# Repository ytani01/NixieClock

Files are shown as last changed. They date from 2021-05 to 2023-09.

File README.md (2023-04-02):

# NixiClock

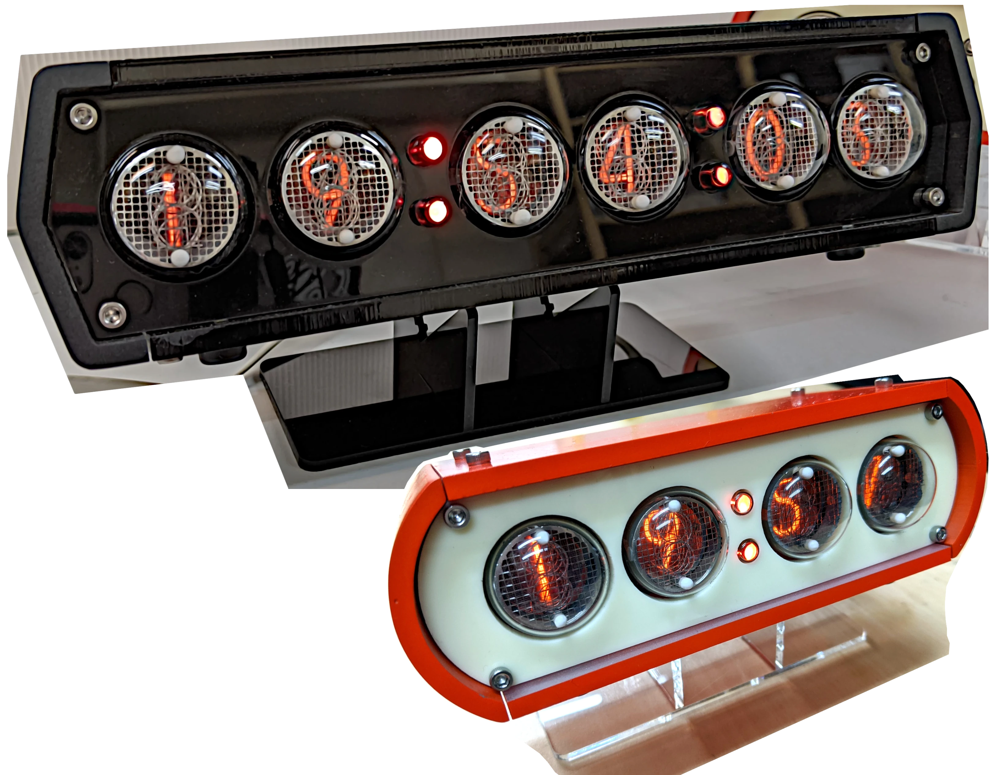
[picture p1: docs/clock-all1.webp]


現在入手困難な、本物のニキシー管を使った時計です。

レトロな外観ではありますが、
WiFi経由でインターネット上の時刻サーバーから、
正確な時刻を取得して、
常に正確な時刻を刻みます。

* WiFi経由で、自動的に時刻合わせ

  インターネット上の時刻サーバー(NTPサーバー)から
  正確な時刻を取得するので、時刻合わせが不要です。
  
  WiFi設定は、スマホで行います。

  (WiFi環境がない場合は、マニュアルで時刻設定することもできます。)

* 明るさの調節

  暗い部屋で眩しいときは、明るさを調整できます。

* 日付表示 可能

## 1. コロン表示の意味

* 【日付表示のとき点滅】WiFi接続 OK

  インターネット経由で、自動的に時刻合わせが行われています。
  
  [ボタン0] ダブルクリックで、``WiFi設定モード``にすることで、
  自動的な時刻合わせを停止することもできます
  (インターネット通信を停止します)。

* 【日付表示のとき点灯】WiFi接続 なし (WiFi設定モード)

  スマホを使って、本時計の WiFiを設定するか、
  マニュアル操作で時刻を設定してください。

  設定した時刻は、電源を切っても保存されます。

  WiFi設定ができているのに、電波の状態などで接続が切れた場合は、
  [ボタン0] ダブルクリックすると、時計が再起動し、WiFi接続を試みます。

## 2. 操作法

## 2.1. ボタン概要

時計表示のとき
```
   +---------- [ボタン0] 日付表示 | ダブルクリック:WiFi設定 | 長押し:手動時刻合わせ
   |  +------- [ボタン1] 日付表示
   |  |  +---- [ボタン2] 明るさ変更 | ダブルクリック:バクライトON/OFF(6桁モデル)
   |  |  |
 --v--v--v--
|  o  o  o  |
 -----------
```

手動で時刻を合わせるとき
```
   +---------- [ボタン0] 長押し: 時刻合わせキャンセル
   |  +------- [ボタン1] 年 -> 月 -> 日 -> 時 -> 分 -> [確定]
   |  |  +---- [ボタン2] カウントアップ
   |  |  |
 --v--v--v--
|  o  o  o  |
 -----------
```

## 2.2 日付表示 [ボタン1]

[ボタン1]を押すと、「年:月:日」を表示します。

数秒後に、時刻表示に戻ります。

## 2.3 明るさ変更 [ボタン2]

明るさを変更(サイクリック)

### 2.4 時刻合わせ (WiFi環境がある場合)

WiFi経由でインターネットに接続すれば、
NTP(Network Time Protocol)を使って、
インターネットから正確な時刻を取得して、
自動的に時刻合わせを行います。

設定したWiFiアクセスポイントの情報は、電源を切っても保存されるので、
毎回設定する必要はありません。

1. [ボタン0] を ダブルクリックしてください。

2. アクセスポイント・モードになり、コロンが点灯します。

3. スマホのWiFi設定で、「NIXIE_CLOCK_XXXXXXXX」に接続してください。

4. 接続すると、ブラウザが自動起動されます。

5. SSIDを設定し、保存してください。

6. [OK]で、時計が再起動再起動します。

7. スマホのWiFi設定を元に戻してください。

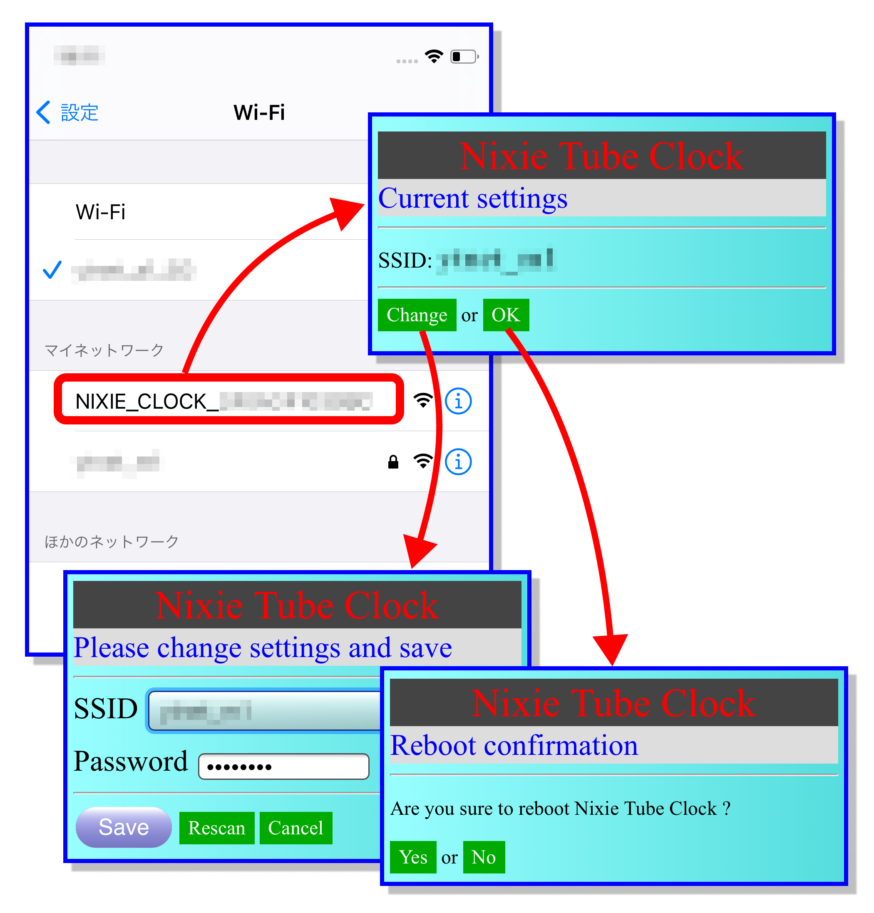
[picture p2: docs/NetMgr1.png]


### 2.5 時刻合わせ (手動)

RTC(Real Time Clock)が、バッテリーでバックアップされているので、
電源を入れ直しても、時刻合わせをし直す必要はありません。

1. [ボタン0] を 長押しして、時刻設定モードに移行

   年:月:日 の表示になり、年(下二桁)が点滅します。

2. 以下

   年 -> 月 -> 日 -> 時 -> [確定]
    
   の順番で設定します。
   (秒は、常に「00」)
   
2. [ボタン2] で 点滅している数値がカウントアップ

3. [ボタン1] で 数値が確定

   次に進みます。

4. 「分」を確定すると、
   時刻が設定され、
   時計表示に戻ります。
   
5. 設定を中断したい場合は、
   [ボタン0] を長押ししてください。

   (元の時刻に戻ります)

(WiFi経由でインターネットに接続している場合は、
この手順で時刻を変更しても、
定期的にインターネットから時刻を取得して補正されます。)

## 9. 開発環境

* Arduino IDE 1.8.15(Windows store 1.8.49.0) on Windows 10
  - ボード・ライブラリ: ESP32 1.0.6
  - RTCライブラリ: RTClib by Adafruit 2.1.0
  - NeoPixelライブラリ: Adafruit NeoPixel 1.11.0
  
### 9.1 ボードマネージャーの設定

[ファイル]-[環境設定]-[追加のボードマネージャのURL]
```
https://raw.githubusercontent.com/espressif/arduino-esp32/gh-pages/package_esp32_index.json
```

### 9.2 ボードの設定

| | |
|--|--|
| ボード | ESP32 Dev Module |
| Upload Speed | 921600 |
| CPU Frequency | 240Mhz(WiFi/BT) |
| Flash Frequency | 80MHz |
| Flash Size | 4MB(32Mb) |
| Partition Scheme | Default 4MB with spiffs(1.2MB APP/1.5MB SPIFFS) |

## A. References

* [github: arduino-esp32](https://github.com/espressif/arduino-esp32/)

* [github: EspExceptionDecoder(スタックトレース表示)](https://github.com/me-no-dev/EspExceptionDecoder/releases/)
  [注意] Microsoft Store の Arduino IDE はNG

* [NeoPixelBus](https://github.com/Makuna/NeoPixelBus)

* [NeoPixel（WS2812B）の制御 その2 (SPI)](https://nuneno.cocolog-nifty.com/blog/2018/05/neopixelws281-1.html)

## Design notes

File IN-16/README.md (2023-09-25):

#

## ArduinoIDE 設定

ボード: ESP32S3 dev module
``` text
 USB CDC On Boot: Disabled
 CPU Frequencdy: 240MHz(WiFi)
*Core Debug Level: Debug
 USB DFU On Boot: Disabled
 Erase All Flash Befor Sketch Upload: Disabled
 Events Run On: Core 1
 Flash Mode: QIO 80MHz
 Flash Size: 4MB(32Mg)
 JTAG Adapter: Disabled
 Arduino Runs On: Core1
 USB Firmware MSC On Boot: Disabled
 Partition Scheme: Default 4MB with spiffs(1.2MB APP/1.5MB SPIFFS)
 PSRAM: Disabled
 Upload Mode: UART0/Hardware CDC
*Upload Speed: 921600
 USB Mode: Hardware CDC and JTAG
```

## [BOOT],[RST]

[BOOT]を押しながら、[RST]をクリック
→ DFU(Device Firmware Update) mode

## PINS

```
constexpr int PIN_SDA = 9;
constexpr int PIN_SCL = 8;

constexpr int PIN_BTN_UP = 18;
constexpr int PIN_BTN_DOWN = 17;
constexpr int PIN_BTN_MODE = 14;
```

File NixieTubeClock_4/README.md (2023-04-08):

# NixiClock



現在入手困難な、本物のニキシー管を使った時計です。

レトロな外観ではありますが、
WiFi経由でインターネット上の時刻サーバーから、
正確な時刻を取得して、
常に正確な時刻を刻みます。

* WiFi経由で、自動的に時刻合わせ

  インターネット上の時刻サーバー(NTPサーバー)から
  正確な時刻を取得するので、時刻合わせが不要です。
  
  WiFi設定は、スマホで行います。

  (WiFi環境がない場合は、マニュアルで時刻設定することもできます。)

* 明るさの調節

  暗い部屋で眩しいときは、明るさを調整できます。

* 日付表示 可能

## 1. コロン表示の意味

* 【日付表示のとき点滅】WiFi接続 OK

  インターネット経由で、自動的に時刻合わせが行われています。
  
  [ボタン0] ダブルクリックで、``WiFi設定モード``にすることで、
  自動的な時刻合わせを停止することもできます
  (インターネット通信を停止します)。

* 【日付表示のとき点灯】WiFi接続 なし (WiFi設定モード)

  スマホを使って、本時計の WiFiを設定するか、
  マニュアル操作で時刻を設定してください。

  設定した時刻は、電源を切っても保存されます。

  WiFi設定ができているのに、電波の状態などで接続が切れた場合は、
  [ボタン0] ダブルクリックすると、時計が再起動し、WiFi接続を試みます。

## 2. 操作法

## 2.1. ボタン概要

時計表示のとき
```
   +---------- [Button0] 日付表示 | 長押し:手動時刻合わせ
   |  +------- [Button1] ファンクションキー
   |  |  +---- [Button2] 明るさ変更 | ダブルクリック:バクライトON/OFF(6桁モデル)
   |  |  |
 --v--v--v--
|  o  o  o  |
 -----------
 
    [Button1]+[Button0]: WiFi設定
    [Button1]+[Button2]: 最大輝度(テスト用)
    [Button1]+[Button2]長押し: ヒーリングモード
 
```

手動で時刻を合わせるとき
```
   +---------- [ボタン0] 長押し: 時刻合わせキャンセル
   |  +------- [ボタン1] 年 -> 月 -> 日 -> 時 -> 分 -> [確定]
   |  |  +---- [ボタン2] カウントアップ
   |  |  |
 --v--v--v--
|  o  o  o  |
 -----------
```

ヒーリングモード
```
   +---------- [ボタン0] 数字選択
   |  +------- [ボタン1] 桁選択
   |  |  +---- [ボタン2] なし
   |  |  |
 --v--v--v--
|  o  o  o  |
 -----------
```

## 2.2 日付表示 [ボタン1]

[ボタン1]を押すと、「年:月:日」を表示します。

数秒後に、時刻表示に戻ります。

## 2.3 明るさ変更 [ボタン2]

明るさを変更(サイクリック)

### 2.4 時刻合わせ (WiFi環境がある場合)

WiFi経由でインターネットに接続すれば、
NTP(Network Time Protocol)を使って、
インターネットから正確な時刻を取得して、
自動的に時刻合わせを行います。

設定したWiFiアクセスポイントの情報は、電源を切っても保存されるので、
毎回設定する必要はありません。

1. [ボタン0] を ダブルクリックしてください。

2. アクセスポイント・モードになり、コロンが点灯します。

3. スマホのWiFi設定で、「NIXIE_CLOCK_XXXXXXXX」に接続してください。

4. 接続すると、ブラウザが自動起動されます。

5. SSIDを設定し、保存してください。

6. [OK]で、時計が再起動再起動します。

7. スマホのWiFi設定を元に戻してください。



### 2.5 時刻合わせ (手動)

RTC(Real Time Clock)が、バッテリーでバックアップされているので、
電源を入れ直しても、時刻合わせをし直す必要はありません。

1. [ボタン0] を 長押しして、時刻設定モードに移行

   年:月:日 の表示になり、年(下二桁)が点滅します。

1. 以下

   年 -> 月 -> 日 -> 時 -> [確定]
    
   の順番で設定します。
   (秒は、常に「00」)
   
1. [ボタン2] で 点滅している数値がカウントアップ

1. [ボタン1] で 数値が確定

   次に進みます。

1. 「分」を確定すると、
   時刻が設定され、
   時計表示に戻ります。
   
1. 設定を中断したい場合は、
   [ボタン0] を長押ししてください。

   (元の時刻に戻ります)

(WiFi経由でインターネットに接続している場合は、
この手順で時刻を変更しても、
定期的にインターネットから時刻を取得して補正されます。)

### 2.6 数字の表示が一部かけるときの対策 (ヒーリングモード)

以下の操作で改善することがあります。

1. ヒーリングモードにする

1. 桁選択: [ボタン2] で桁を選択

1. 数字選択: [ボタン3] で数字選択

1. 約3分後に自動的に時刻表に戻ります。

## 9. 開発環境

* Arduino IDE 1.8.15(Windows store 1.8.49.0) on Windows 10
  - ボード・ライブラリ: ESP32 1.0.6
  - RTCライブラリ: RTClib by Adafruit 2.1.0
  - NeoPixelライブラリ: Adafruit NeoPixel 1.11.0
  
### 9.1 ボードマネージャーの設定

[ファイル]-[環境設定]-[追加のボードマネージャのURL]
```
https://raw.githubusercontent.com/espressif/arduino-esp32/gh-pages/package_esp32_index.json
```

### 9.2 ボードの設定

| | |
|--|--|
| ボード | ESP32 Dev Module |
| Upload Speed | 921600 |
| CPU Frequency | 240Mhz(WiFi/BT) |
| Flash Frequency | 80MHz |
| Flash Size | 4MB(32Mb) |
| Partition Scheme | Default 4MB with spiffs(1.2MB APP/1.5MB SPIFFS) |

## A. References

* [github: arduino-esp32](https://github.com/espressif/arduino-esp32/)

* [github: EspExceptionDecoder(スタックトレース表示)](https://github.com/me-no-dev/EspExceptionDecoder/releases/)
  [注意] Microsoft Store の Arduino IDE はNG

* [NeoPixelBus](https://github.com/Makuna/NeoPixelBus)

* [NeoPixel（WS2812B）の制御 その2 (SPI)](https://nuneno.cocolog-nifty.com/blog/2018/05/neopixelws281-1.html)

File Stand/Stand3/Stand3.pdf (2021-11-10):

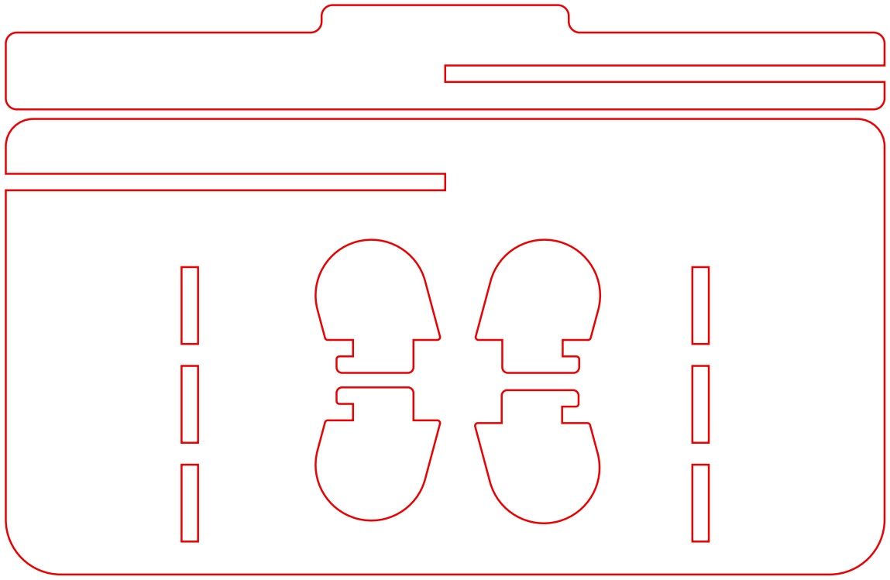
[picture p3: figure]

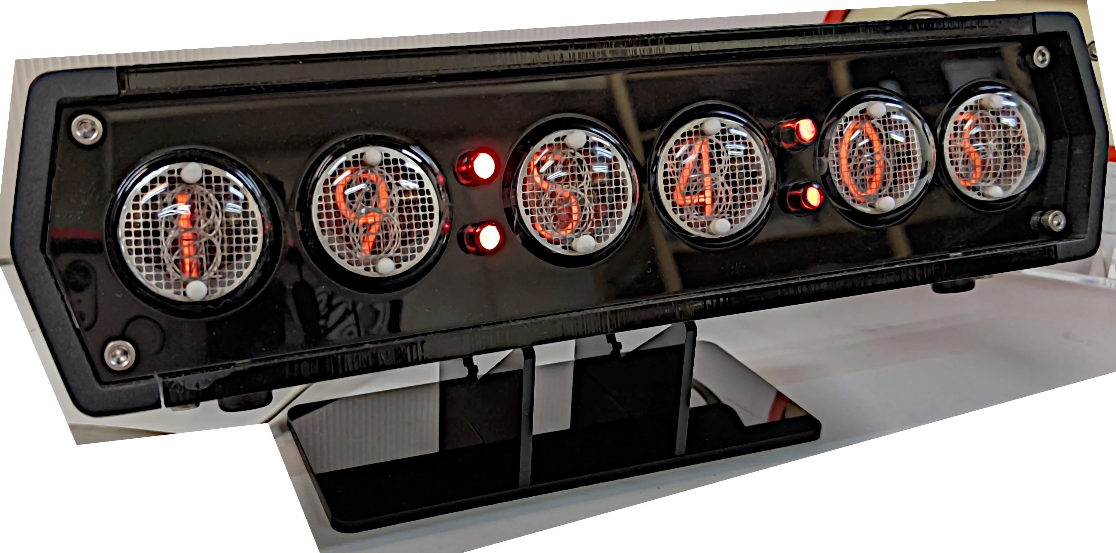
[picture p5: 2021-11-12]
docs/clock-6a.webp

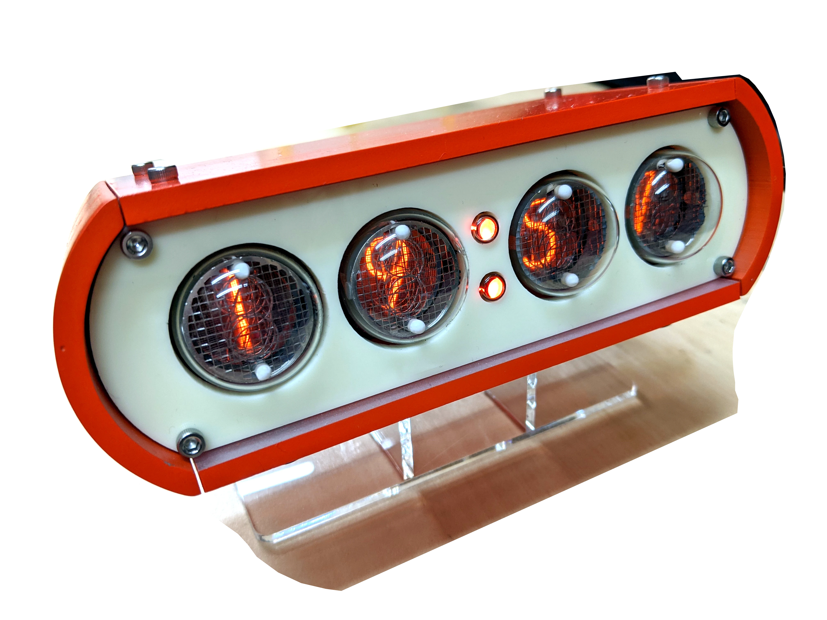
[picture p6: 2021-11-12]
docs/clock-4a.webp

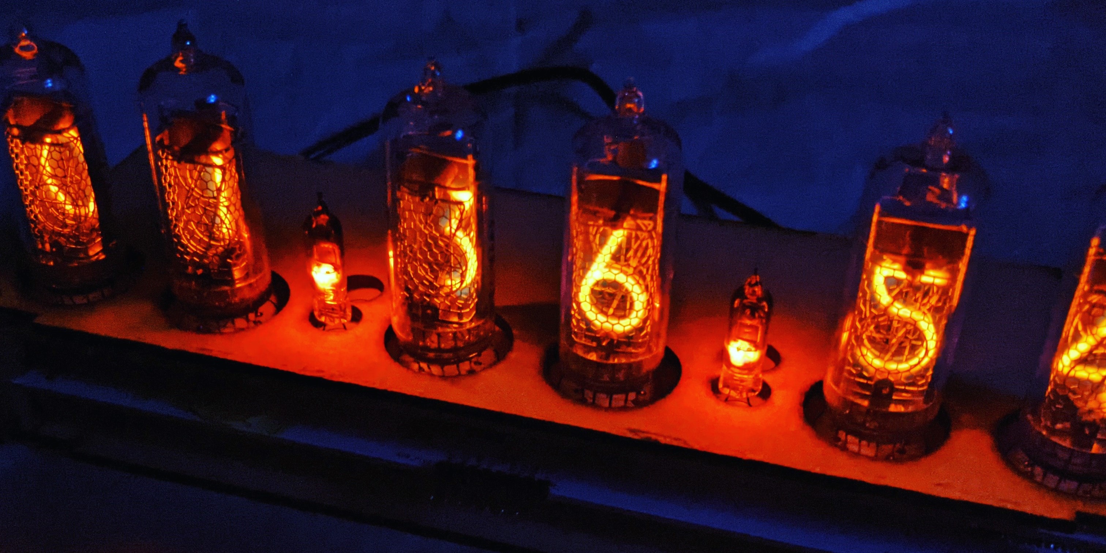
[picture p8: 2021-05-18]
docs/clock1.jpg

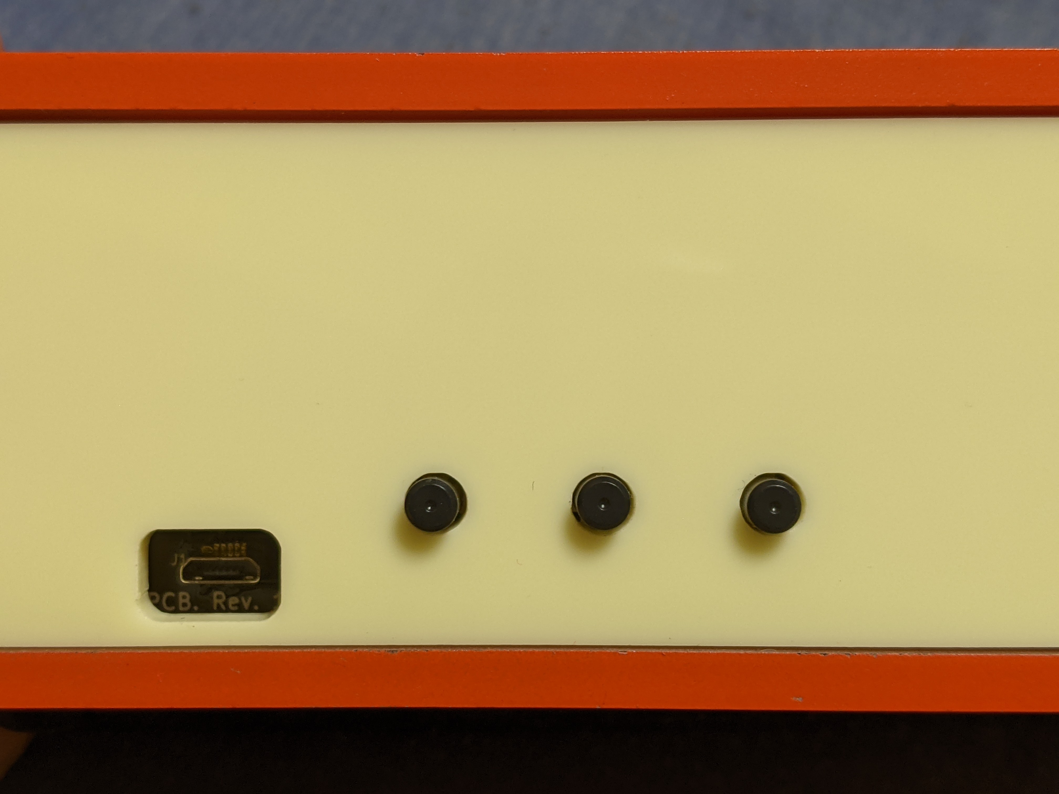
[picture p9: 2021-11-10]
docs/buttons0.jpg

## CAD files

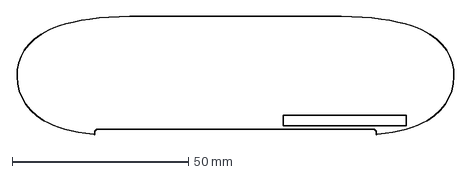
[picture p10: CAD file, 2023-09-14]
IN-16/fromTakao/IN-16_Nixie_Clock/drawing/header_placement_nixie.dxf
124.5 x 33.5 mm

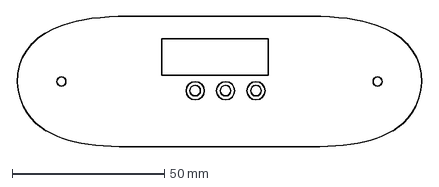
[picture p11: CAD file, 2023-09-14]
IN-16/fromTakao/IN-16_Nixie_Clock/drawing/svg/Bottom_acrylic_0819.dxf
133.6 x 43.0 mm

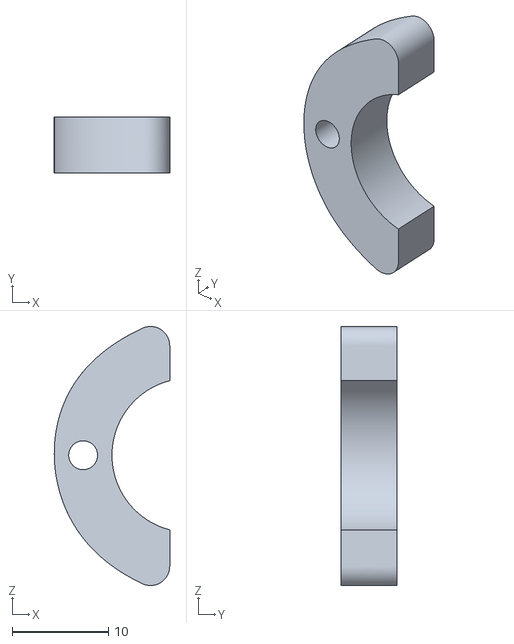
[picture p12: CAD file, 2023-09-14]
IN-16/fromTakao/IN-16_Nixie_Clock/model/Spacer_3DPrint_Mid_0817.stl
12.0 x 5.80 x 26.9

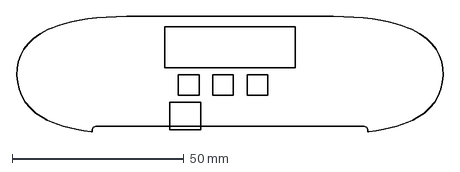
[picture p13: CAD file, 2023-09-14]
IN-16/fromTakao/IN-16_Nixie_Clock/drawing/lcd_typec_placement.dxf
124.5 x 33.5 mm

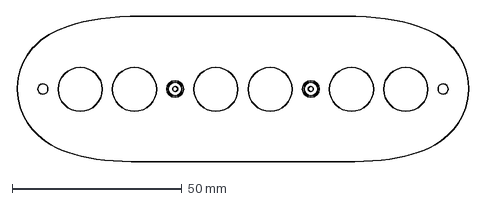
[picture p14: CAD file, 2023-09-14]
IN-16/fromTakao/IN-16_Nixie_Clock/drawing/svg/Top_acrylic_0819.dxf
133.6 x 43.0 mm

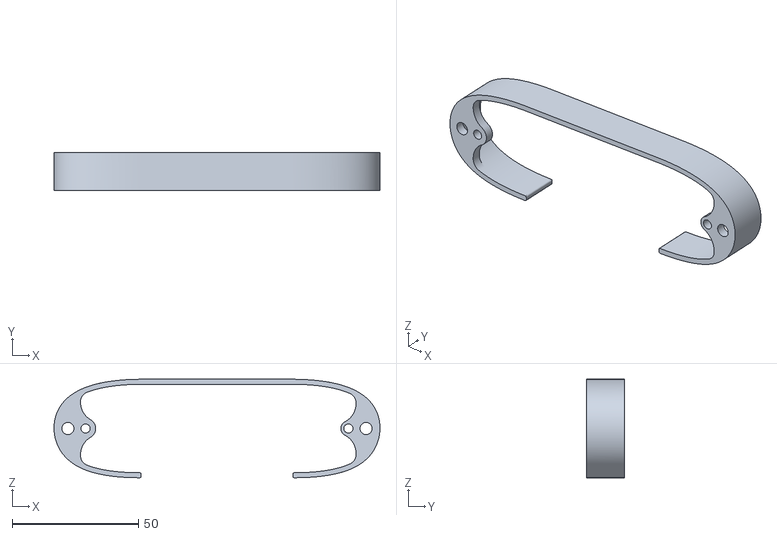
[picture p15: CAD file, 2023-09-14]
IN-16/fromTakao/IN-16_Nixie_Clock/model/Side_Wall_0817.stl
129.0 x 15.0 x 39.0

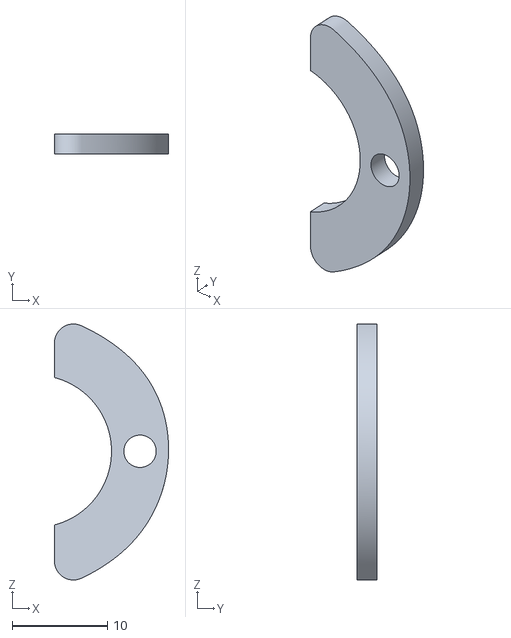
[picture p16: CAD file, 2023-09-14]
IN-16/fromTakao/IN-16_Nixie_Clock/drawing/Spacer_3DPrint_Top_0824.stl
12.0 x 2.10 x 26.9

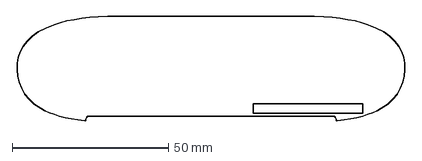
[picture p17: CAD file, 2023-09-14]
IN-16/fromTakao/IN-16_Nixie_Clock/drawing/header_placemenr.dxf
124.5 x 33.5 mm

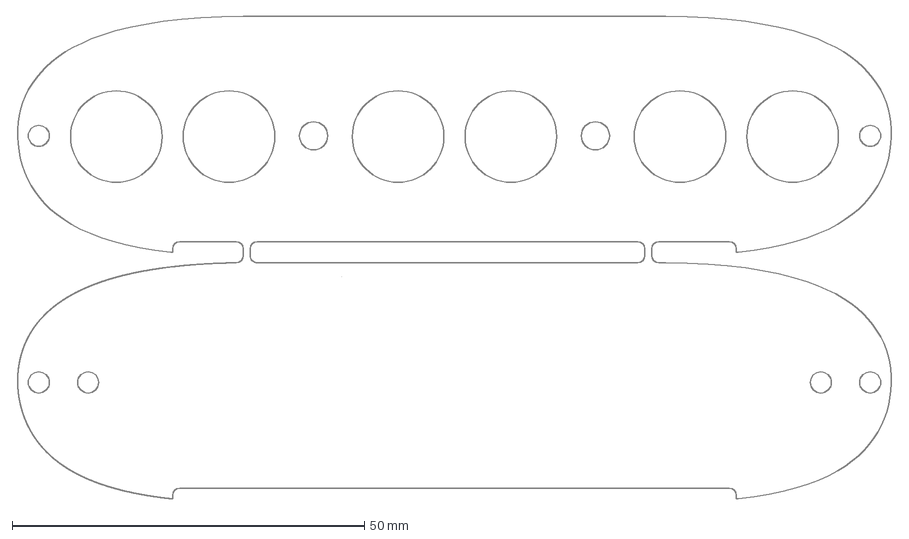
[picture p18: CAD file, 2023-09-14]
IN-16/fromTakao/IN-16_Nixie_Clock/drawing/IN-16_6digit_PCB_outline.dxf
124.5 x 68.5 mm

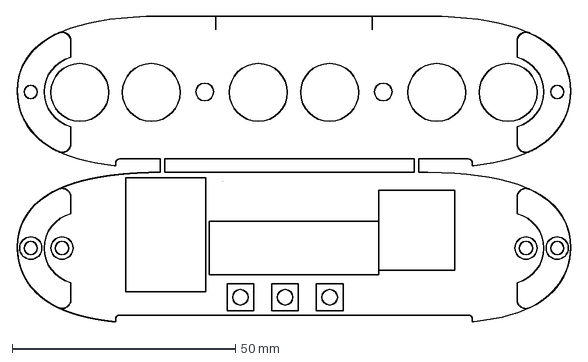
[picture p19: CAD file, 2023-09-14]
IN-16/fromTakao/IN-16_Nixie_Clock/drawing/IN-16_6digit_PCB_drawing.dxf
124.5 x 68.5 mm

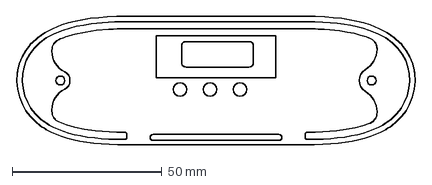
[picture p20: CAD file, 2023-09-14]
IN-16/fromTakao/IN-16_Nixie_Clock/drawing/Bottom_Drawing_0827.dxf
133.6 x 43.0 mm

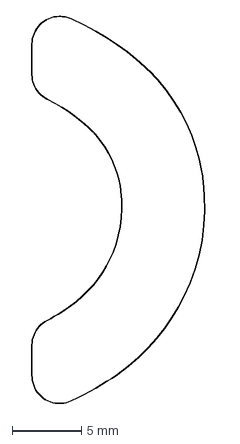
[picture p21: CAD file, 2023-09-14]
IN-16/fromTakao/IN-16_Nixie_Clock/drawing/Bottom_Rubber_Foot.dxf
12.7 x 28.0 mm

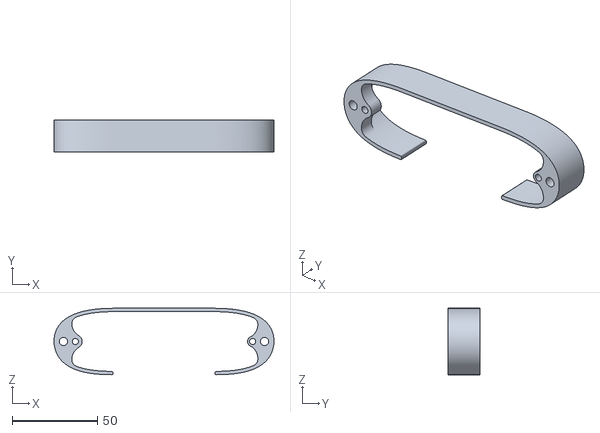
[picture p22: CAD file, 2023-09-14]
IN-16/fromTakao/IN-16_Nixie_Clock/drawing/Side_Wall_0824.stl
129.0 x 19.0 x 39.0

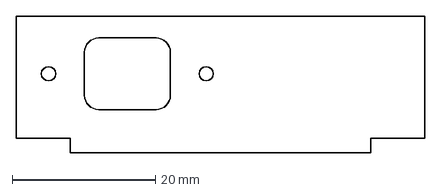
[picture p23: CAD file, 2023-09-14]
IN-16/fromTakao/IN-16_Nixie_Clock/drawing/Side_wall_back.dxf
57.0 x 19.0 mm

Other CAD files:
IN-16/fromTakao/IN-16_Nixie_Clock/model/Spacer_3DPrint_Top_0817.stl
IN-16/fromTakao/IN-16_Nixie_Clock/drawing/Bottom_Drawing_0821.dxf
IN-16/fromTakao/IN-16_Nixie_Clock/drawing/Top_Drawing_0827.dxf
IN-16/fromTakao/IN-16_Nixie_Clock/drawing/IN-16_6digit_Nixie_Base.dxf
IN-16/fromTakao/IN-16_Nixie_Clock/drawing/IN-16_6digit_MCU_Base.dxf
IN-16/fromTakao/IN-16_Nixie_Clock/drawing/Spacer_3DPrint_Mid_0824.stl
IN-16/fromTakao/IN-16_Nixie_Clock/drawing/Top_Drawing_0821.dxf
Stand/Stand1/Stand1.f3d
Stand/Stand2/Stand2.f3d
Stand/Stand3/Stand3.f3d

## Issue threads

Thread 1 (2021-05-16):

表示がちらつく

ytani01, 2021-05-16:
輝度を最大にすると、ちらつかないが、輝度を下げるとちらつく。

ytani01, 2021-05-16:
ESP32ボード・ライブラリ 1.0.5ではちらつかないが、1.0.6(最新版)ではチラツキが発生する。

ytani01, 2021-05-16:
wifi_svr.handleClient() の処理を抜くとチラツキが発生しない。
ライブラリ内の ``WebServer::handleClient()``内部で、``delay(1)``が呼ばれている。
``WebServer::enableDelay(false)``を呼ぶことにより、``delay(1)``を回避できることが判明。

https://github.com/espressif/arduino-esp32/blob/master/libraries/WebServer/src/WebServer.cpp
```
 :
void WebServer::handleClient() {
  if (_currentStatus == HC_NONE) {
    WiFiClient client = _server.available();
    if (!client) {
      if (_nullDelay) {
        delay(1);
      }
      return;
    }
 :
void WebServer::enableDelay(boolean value) {
  _nullDelay = value;
}
 :
```

ytani01, 2021-05-16:
``WebServer``を初期化するときに、``WebServer::enableDelay(false)``を呼ぶようにしたら、チラツキがなくなった。

Closed 2021-05-16.

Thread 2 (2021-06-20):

(xQueueGenericReceive)- assert failed!

ytani01, 2021-06-20:
時刻変更モードから戻ろうとして、BTN0を長押ししたら、下記のエラーで再起動した。
再現性はなく、ごくまれに起きる。

```
/home/runner/work/esp32-arduino-lib-builder/esp32-arduino-lib-builder/esp-idf/components/freertos/queue.c:1446 (xQueueGenericReceive)- assert failed!
```

```
Decoding stack results
0x40089134: invoke_abort at /home/runner/work/esp32-arduino-lib-builder/esp32-arduino-lib-builder/esp-idf/components/esp32/panic.c line 156
0x400893b1: abort at /home/runner/work/esp32-arduino-lib-builder/esp32-arduino-lib-builder/esp-idf/components/esp32/panic.c line 171
0x4008a127: xQueueGenericReceive at /home/runner/work/esp32-arduino-lib-builder/esp32-arduino-lib-builder/esp-idf/components/freertos/queue.c line 1446
0x400ded7d: uartWriteBuf at C:\Users\ytani\AppData\Local\Arduino15\packages\esp32\hardware\esp32\1.0.6\cores\esp32\esp32-hal-uart.c line 363
0x400df389: HardwareSerial::write(unsigned char const*, unsigned int) at C:\Users\ytani\AppData\Local\Arduino15\packages\esp32\hardware\esp32\1.0.6\cores\esp32\HardwareSerial.cpp line 175
0x400df612: Print::write(char const*) at C:\Users\ytani\AppData\Local\Arduino15\packages\esp32\hardware\esp32\1.0.6\cores\esp32/Print.h line 67
0x400df6f5: Print::print(char const*) at C:\Users\ytani\AppData\Local\Arduino15\packages\esp32\hardware\esp32\1.0.6\cores\esp32\Print.cpp line 89
0x4008103e: btn_intr_hdr() at \\wsl$\Ubuntu-20.04\home\ytani\work\NixieClock\NixieTubeClock/NixieTubeClock.ino line 193
0x400810d9: __onPinInterrupt at C:\Users\ytani\AppData\Local\Arduino15\packages\esp32\hardware\esp32\1.0.6\cores\esp32\esp32-hal-gpio.c line 234
0x4008b545: vTaskExitCritical at /home/runner/work/esp32-arduino-lib-builder/esp32-arduino-lib-builder/esp-idf/components/freertos/tasks.c line 4274
0x4008a9e8: xEventGroupWaitBits at /home/runner/work/esp32-arduino-lib-builder/esp32-arduino-lib-builder/esp-idf/components/freertos/event_groups.c line 427
0x400de132: i2cProcQueue at C:\Users\ytani\AppData\Local\Arduino15\packages\esp32\hardware\esp32\1.0.6\cores\esp32\esp32-hal-i2c.c line 1287
0x400de4d7: i2cWrite at C:\Users\ytani\AppData\Local\Arduino15\packages\esp32\hardware\esp32\1.0.6\cores\esp32\esp32-hal-i2c.c line 1629
0x400dd729: TwoWire::writeTransmission(unsigned short, unsigned char*, unsigned short, bool) at C:\Users\ytani\AppData\Local\Arduino15\packages\esp32\hardware\esp32\1.0.6\libraries\Wire\src\Wire.cpp line 144
0x400dd77d: TwoWire::endTransmission(bool) at C:\Users\ytani\AppData\Local\Arduino15\packages\esp32\hardware\esp32\1.0.6\libraries\Wire\src\Wire.cpp line 169
0x400dd889: TwoWire::endTransmission() at C:\Users\ytani\AppData\Local\Arduino15\packages\esp32\hardware\esp32\1.0.6\libraries\Wire\src\Wire.cpp line 327
0x400d6748: RTC_DS3231::now() at C:\Users\ytani\Documents\Arduino\libraries\RTClib\RTClib.cpp line 1398
0x400d60ce: loop() at \\wsl$\Ubuntu-20.04\home\ytani\work\NixieClock\NixieTubeClock/NixieTubeClock.ino line 309
0x400e07ed: loopTask(void*) at C:\Users\ytani\AppData\Local\Arduino15\packages\esp32\hardware\esp32\1.0.6\cores\esp32\main.cpp line 23
0x4008a3c2: vPortTaskWrapper at /home/runner/work/esp32-arduino-lib-builder/esp32-arduino-lib-builder/esp-idf/components/freertos/port.c line 143
```

ytani01, 2021-11-06:
しばらく採点してないので、一旦クローズ

Closed 2021-11-06.

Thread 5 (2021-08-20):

NeoPixelがちらつく

ytani01, 2021-08-20:
テスト基盤のNeoPixelを以下、3種類のライブラリでテストしたが、どれもちらつく。
ちらつき方は不規則。

Library
* Adafruit_NeoPixel
* FastLED
* NeoPixelBus

ytani01, 2021-08-20:
市販のNeoPixelと連結して試したところ、市販品はちらつかず、テスト基盤の方のみがちらつく。

市販品: [円形 リング シリアルLED](https://www.amazon.co.jp/gp/product/B07927PLP3/)

ytani01, 2021-08-30:
コンデンサーを付けたら解消された

Closed 2021-08-30.

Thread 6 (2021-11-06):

WiFiがONでもOFFでも、コロンが点滅するようにしたい(from takao)

ytani01, 2021-11-06:
現在の動作は、WiFiがONのときは、コロンが点滅するが、OFFのときは点滅しない(点灯のみ)。
両方とも点滅するようにしたい (from takao)

ytani01, 2021-11-06:
4桁版では、時刻表示のときは、両方とも点滅するが、日付表示のときに、WiFiがONの場合は点滅/OFFの場合は点灯するようにした。

ytani01, 2021-11-06:
> 4桁版では、時刻表示のときは、両方とも点滅するが、日付表示のときに、WiFiがONの場合は点滅/OFFの場合は点灯するようにした。

6桁版でも、同じ仕様にした。

ytani01, 2021-11-09:
高尾くんがOKならクローズしてください。

minori24, 2021-11-11:
OKです。Closeお願いします

Closed 2021-11-11.

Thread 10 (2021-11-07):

時刻変更モードのときに、数字の``1``の点滅タイミングがズレて、消えることもある(from takao)

ytani01, 2021-11-07:

ytani01, 2021-11-07:
1の位が「1」のときだけ、この現象が起こる

ytani01, 2021-11-09:
事象がある程度特定できた。
・輝度を落としているときだけ起こる。最高輝度では起こらない。
・「1」だけじゃなく、他の数字でもたまに消えることがある。
・時刻変更モードの点滅で左右のタイミングがずれるのは仕様 (数字が変化したタイミングで点滅を開始)

【原因】
輝度を落とすために点灯を間引くタイミングと点滅のタイミングがあったときに数字が消えたように見える。

【対策案】
時刻変更モードのときは、必ず最高輝度にする。

ytani01, 2021-11-11:
時刻変更モードのときには、必ず最高輝度になるよう変更。
時刻モードに戻ると、もとの輝度に戻る。
点滅のタイミングは微妙にずれるが、消えることはなくなった。

ytani01, 2021-11-11:
上記現象、全くなくなってはいなかった。
6桁版も4桁版も一番右の桁が「1」で点滅しているときに、タイミングが微妙になる。

原因は不明。以下推測。
・個体差かもしれない。
・ハード的な問題(シフトレジスタ関連?)かもしれない。

実用上は差し支えないため、至急対応すべき問題ではないと思われる。
他の個体でも確認する必要がある。

ytani01, 2023-02-26:
再現しないため、クローズ

Closed 2023-02-26.

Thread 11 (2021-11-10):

(4桁版) 時刻設定時に、ボタン操作した瞬間にリセットがかかることがある

ytani01, 2021-11-10:
【現象】
時刻設定時に、ボタン操作した瞬間にリセットがかかることがある

【分析】
おそらく、ボタン操作時にシリアルにデバッグライトしているためだと推測される。
現在のIDEでは、スタックトレースが表示できなくなってしまったため、詳細は不明。

【対策】
(4桁版のみ) 割り込み処理の中では、一切、シリアルに出力しないようにした。
しばらく様子見。
問題なければ、6桁版にも反映

ytani01, 2021-11-11:
6桁版は、すでに対応していた。

ytani01, 2021-11-11:
いろいろ試したが、今の所問題は解消したように見えるので、クローズします。
また、リセットがかかる事象が発生した場合は、あらたなissueとする。

Closed 2021-11-11.

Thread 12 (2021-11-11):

4桁版に比べ6桁版が暗いように見える

ytani01, 2021-11-11:
【現象】全体的に、4桁版に比べ、6桁版の暗いように見える。

【原因】不明。
・最大輝度で点灯している場合、ソフト的には間欠的に消灯などは行っていないため、ハード的な問題かもしれない。
・個体差かもしれない。
・ニキシー管の劣化の問題かもしれない。

【対策】様子見
実用上は差し支えないと考えられる。
他の個体でも確認し、再現性の確認が必要。

ytani01, 2023-02-26:
特に問題になってないので一旦クローズ

Closed 2023-02-26.

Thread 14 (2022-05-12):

手動で時刻設定するときに、カウントアップのボタンを押しているとリセットがかかることがある

ytani01, 2022-05-12:
from Takao
```
(4桁版で)
手動で時刻設定するときに、カウントアップのボタンを押しているとリセットがかかることがあります。長押しではなく複数回短押しです
```
[log.txt](https://github.com/ytani01/NixieClock/files/8677401/log.txt)

ytani01, 2022-05-14:
from Takao
古いソフトを使っていたため、#11 と同じ症状が出てしまった。
最新版に更新したら解決

Closed 2022-05-14.

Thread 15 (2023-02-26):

ニキシー管のヒーリング機能追加

ytani01, 2023-02-26:
※以下、 facebookメッセンジャーより
※ from Minori Takao
ニキシー管のヒーリングの件ですが、電流制限抵抗を変えることにしました。
通常時は最大輝度で62%程度のPWMになるとベストです。このとき定格の2.5mA流れます。ヒーリングをかけるときはPWM100%で4mA流れる計算です

時間はとりあえず3分にしましょう
ラボに置いていた時計は抵抗が大きめなので、次お会いした時に付け替えます。

ytani01, 2023-04-08:
コロンは不要。

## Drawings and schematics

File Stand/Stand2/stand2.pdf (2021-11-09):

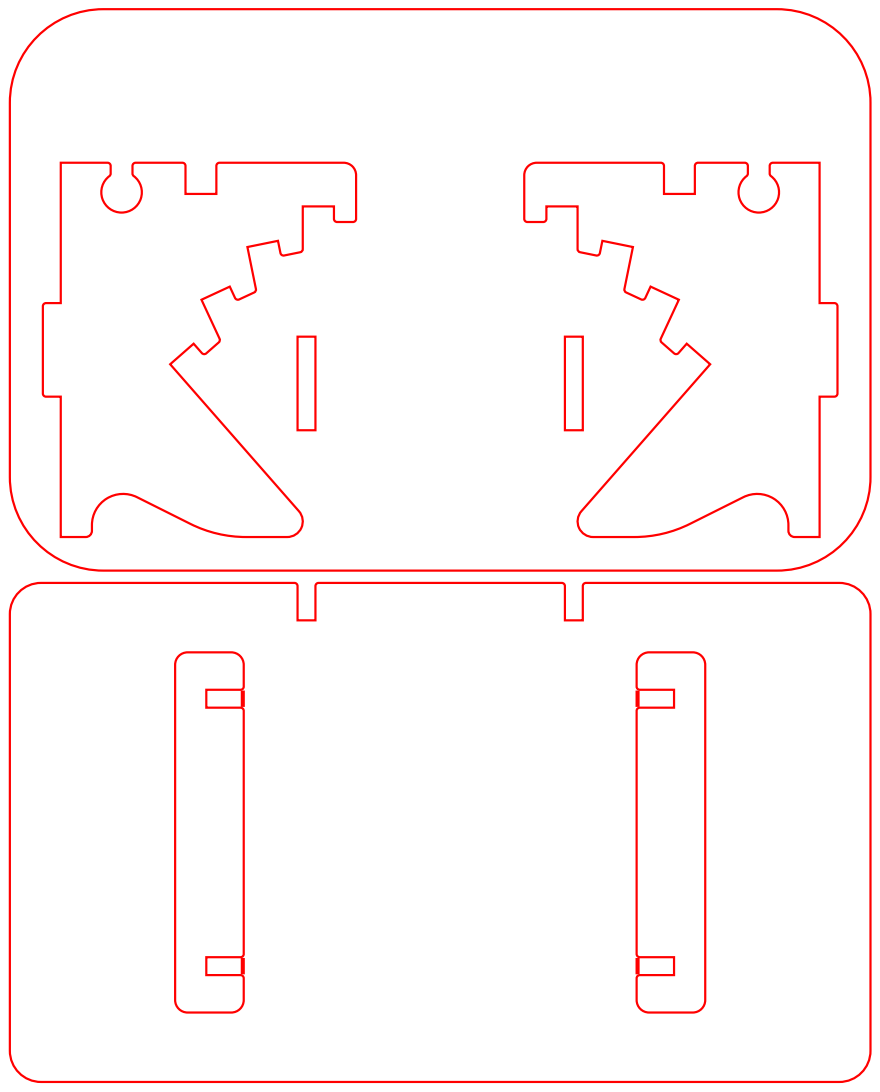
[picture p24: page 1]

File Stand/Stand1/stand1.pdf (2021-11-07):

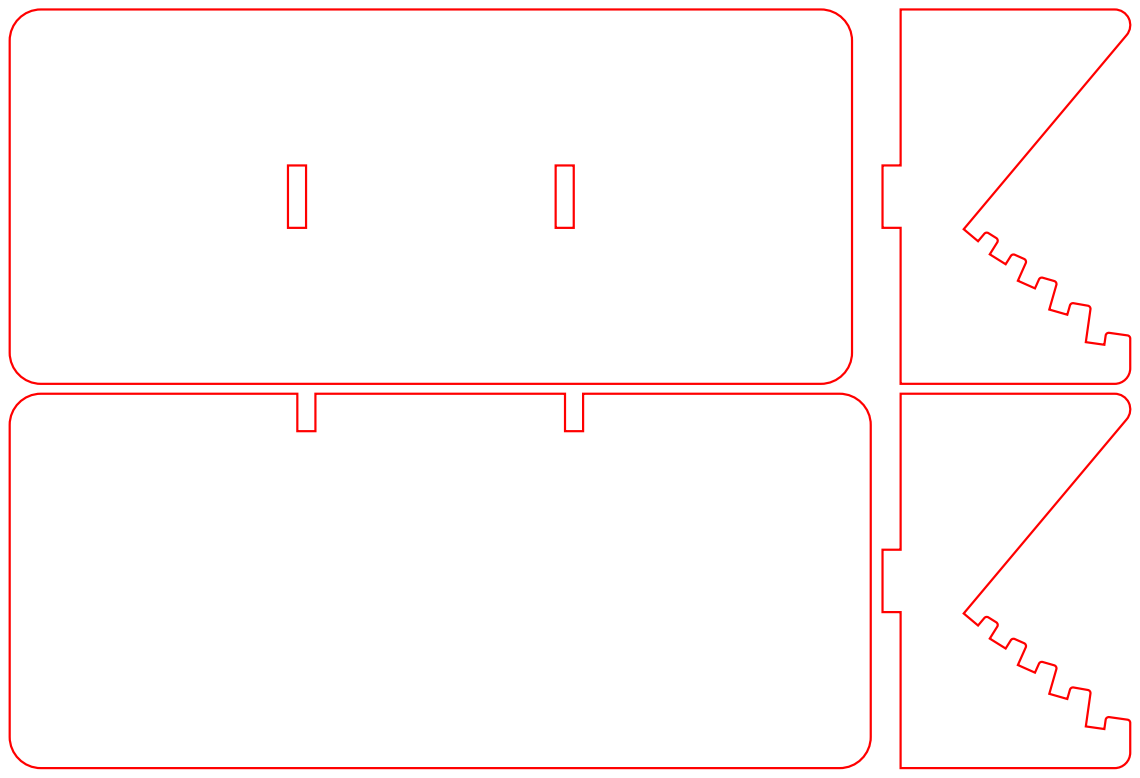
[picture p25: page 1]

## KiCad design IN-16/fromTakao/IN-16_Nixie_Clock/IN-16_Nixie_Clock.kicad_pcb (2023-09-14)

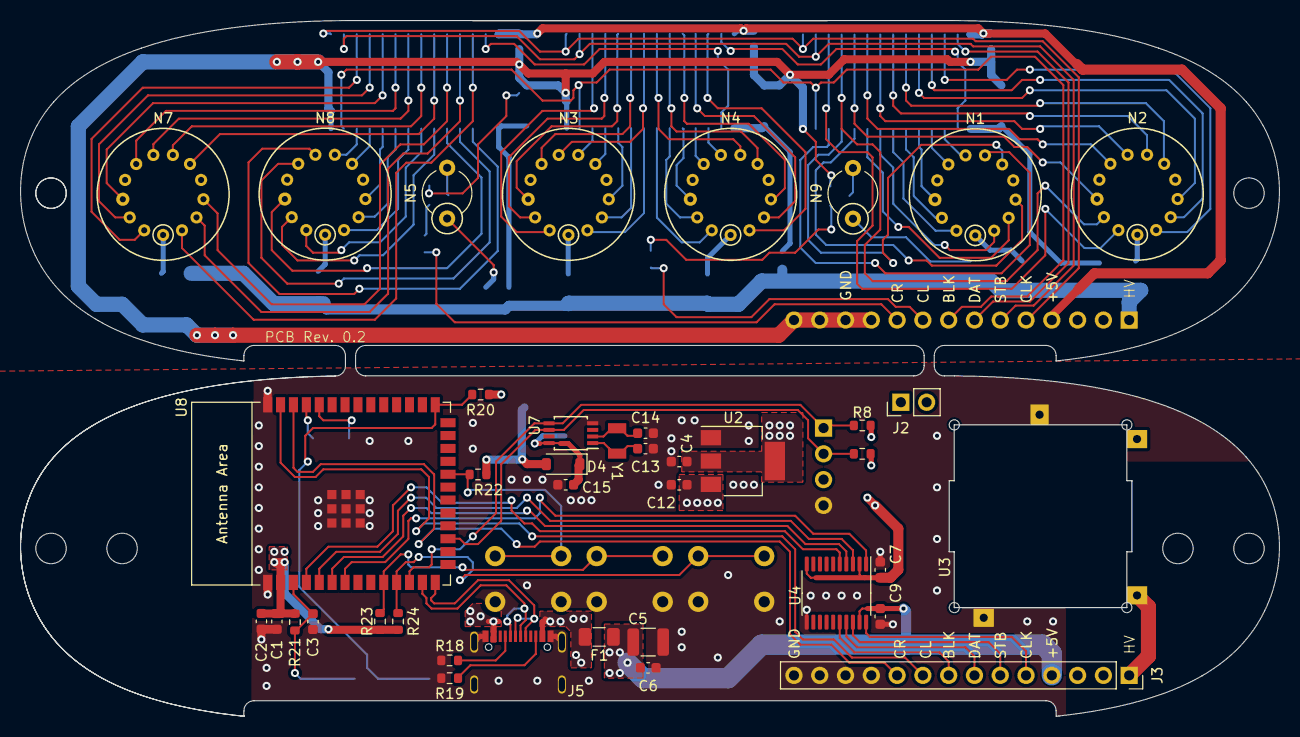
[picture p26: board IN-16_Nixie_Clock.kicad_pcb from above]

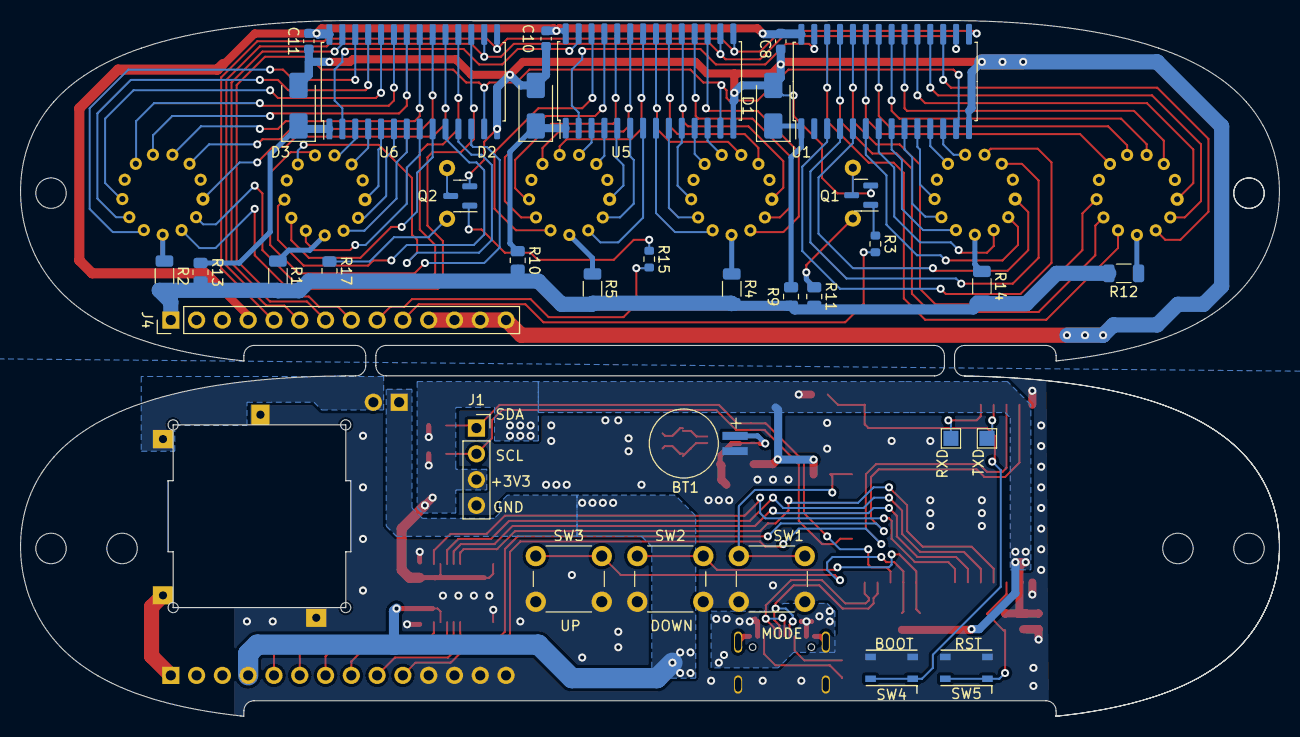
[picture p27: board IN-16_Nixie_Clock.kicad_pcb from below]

Board: 2 copper layers, 124.0 x 68.5 mm, 74 parts (34 on the bottom side), 117 nets.

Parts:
BT1: MS621FE FL11E
C1: 22uF; C_0603_1608Metric
C2, C3, C6, C7, C8, C9, C10, C11, C15: 100nF; C_0603_1608Metric
C4, C12: 10uF; C_0603_1608Metric
C5: 4.7uF; C_1210_3225Metric
C13, C14: 7pF; C_0603_1608Metric
D1, D2, D3: 82V; D_SMA
D4: B0540W-7-F; D_SOD-123
F1: Fuse; Fuse_1206_3216Metric
J1: Conn_LCD; PinSocket_1x04_P2.54mm_Vertical
J2: Jumper_HV_SW; PinHeader_1x02_P2.54mm_Vertical
J3: Conn_MCU_Base; PinSocket_1x14_P2.54mm_Vertical
J4: Conn_Nix_Base; PinHeader_1x14_P2.54mm_Vertical
J5: USB_C_Receptacle_USB2.0; GT-USB-7010AN
N1, N2, N3, N4, N7, N8: IN-16
N5, N9: INS-1; NE-2
Q1, Q2: MMBTA42; SOT-23
R1, R2, R4, R5, R12, R14: 22k_1210; R_1206_3216Metric
R3, R7, R8, R15, R20, R21: 10k; R_0603_1608Metric
R9, R10, R13: 100k_0805; R_0805_2012Metric
R11, R17: 220k_0805; R_0805_2012Metric
R18, R19: 5.1k; R_0603_1608Metric
R22, R23, R24: 1k; R_0603_1608Metric
SW1, SW2, SW3: SW_SPST; SW_PUSH_6mm_H4.3mm
SW4: SW_BOOT; SW_Tactile_SKRPACE010
SW5: SW_RST; SW_Tactile_SKRPACE010
TP1, TP2: TestPoint; TestPoint_Pad_1.5x1.5mm
U1, U5, U6: HV5812; SOIC-28W_7.5x17.9mm_P1.27mm
U2: AMS1117-3.3; SOT-223-3_TabPin2
U3: HV_Power_Supply; NCH8200HV_Sink
U4: TXS0108EPWR; TSSOP-20_4.4x6.5mm_P0.65mm
U7: PCF8563TS/5; TSSOP-8_3x3mm_P0.65mm
U8: ESP32-S3-WROOM-1
Y1: Crystal; Crystal_FC135

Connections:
+3V3: C1.1, C2.1, C4.1, C7.1, D4.2 (A), J1.3, R7.2, R8.2, R20.2, R21.2, R22.2, R23.2, R24.2, U2.2 (VO), U4.2 (VCCA), U4.10 (OE), U8.2 (3V3)
+5V: C5.1, C6.1, C9.1, C12.1, F1.1, J2.1, J3.4, U2.3 (VI), U4.19 (V)
+5V_C: C8.1, C10.1, C11.1, J4.4, U1.28 (VDD), U5.28 (VDD), U6.28 (VDD)
+HV: J3.1, U3.4 (VOUT)
+HV_C: J4.1, R1.2, R2.2, R4.2, R5.2, R9.2, R10.2, R11.2, R12.2, R13.2, R14.2, R17.2
/EN: C3.1, R21.1, SW5.1 (A), U8.3 (EN)
/IO0: R20.1, SW4.1 (A), U8.27 (GPIO0/BOOT)
/Nixie_Driver/AN_A0: N7.13 (K0), U1.17 (HVOUT10)
/Nixie_Driver/AN_A1: N7.2 (K1), U1.26 (HVOUT1)
/Nixie_Driver/AN_A2: N7.9 (K2), U1.20 (HVOUT7)
/Nixie_Driver/AN_A3: N7.4 (K3), U1.24 (HVOUT3)
/Nixie_Driver/AN_A4: N7.6 (K4), U1.23 (HVOUT4)
/Nixie_Driver/AN_A5: N7.7 (K5), U1.22 (HVOUT5)
/Nixie_Driver/AN_A6: N7.8 (K6), U1.21 (HVOUT6)
/Nixie_Driver/AN_A7: N7.3 (K7), U1.25 (HVOUT2)
/Nixie_Driver/AN_A8: N7.11 (K8), U1.19 (HVOUT8)
/Nixie_Driver/AN_A9: N7.12 (K9), U1.18 (HVOUT9)
/Nixie_Driver/AN_B0: N8.13 (K0), U1.7 (HVOUT16)
/Nixie_Driver/AN_B1: N8.2 (K1), U1.8 (HVOUT15)
/Nixie_Driver/AN_B2: N8.9 (K2), U1.4 (HVOUT19)
/Nixie_Driver/AN_B3: N8.4 (K3), U1.10 (HVOUT13)
/Nixie_Driver/AN_B4: N8.6 (K4), U1.11 (HVOUT12)
/Nixie_Driver/AN_B5: N8.7 (K5), U1.12 (HVOUT11)
/Nixie_Driver/AN_B6: N8.8 (K6), U1.3 (HVOUT20)
/Nixie_Driver/AN_B7: N8.3 (K7), U1.9 (HVOUT14)
/Nixie_Driver/AN_B8: N8.11 (K8), U1.5 (HVOUT18)
/Nixie_Driver/AN_B9: N8.12 (K9), U1.6 (HVOUT17)
/Nixie_Driver/AN_C0: N3.13 (K0), U5.17 (HVOUT10)
/Nixie_Driver/AN_C1: N3.2 (K1), U5.8 (HVOUT15)
/Nixie_Driver/AN_C2: N3.9 (K2), U5.20 (HVOUT7)
/Nixie_Driver/AN_C3: N3.4 (K3), U5.10 (HVOUT13)
/Nixie_Driver/AN_C4: N3.6 (K4), U5.11 (HVOUT12)
/Nixie_Driver/AN_C5: N3.7 (K5), U5.12 (HVOUT11)
/Nixie_Driver/AN_C6: N3.8 (K6), U5.21 (HVOUT6)
/Nixie_Driver/AN_C7: N3.3 (K7), U5.9 (HVOUT14)
/Nixie_Driver/AN_C8: N3.11 (K8), U5.19 (HVOUT8)
/Nixie_Driver/AN_C9: N3.12 (K9), U5.18 (HVOUT9)
/Nixie_Driver/AN_D0: N4.13 (K0), U5.7 (HVOUT16)
/Nixie_Driver/AN_D1: N4.2 (K1), U5.26 (HVOUT1)
/Nixie_Driver/AN_D2: N4.9 (K2), U5.4 (HVOUT19)
/Nixie_Driver/AN_D3: N4.4 (K3), U5.24 (HVOUT3)
/Nixie_Driver/AN_D4: N4.6 (K4), U5.23 (HVOUT4)
/Nixie_Driver/AN_D5: N4.7 (K5), U5.22 (HVOUT5)
/Nixie_Driver/AN_D6: N4.8 (K6), U5.3 (HVOUT20)
/Nixie_Driver/AN_D7: N4.3 (K7), U5.25 (HVOUT2)
/Nixie_Driver/AN_D8: N4.11 (K8), U5.5 (HVOUT18)
/Nixie_Driver/AN_D9: N4.12 (K9), U5.6 (HVOUT17)
/Nixie_Driver/AN_E0: N1.13 (K0), U6.7 (HVOUT16)
/Nixie_Driver/AN_E1: N1.2 (K1), U6.8 (HVOUT15)
/Nixie_Driver/AN_E2: N1.9 (K2), U6.4 (HVOUT19)
/Nixie_Driver/AN_E3: N1.4 (K3), U6.10 (HVOUT13)
/Nixie_Driver/AN_E4: N1.6 (K4), U6.11 (HVOUT12)
/Nixie_Driver/AN_E5: N1.7 (K5), U6.12 (HVOUT11)
/Nixie_Driver/AN_E6: N1.8 (K6), U6.3 (HVOUT20)
/Nixie_Driver/AN_E7: N1.3 (K7), U6.9 (HVOUT14)
/Nixie_Driver/AN_E8: N1.11 (K8), U6.5 (HVOUT18)
/Nixie_Driver/AN_E9: N1.12 (K9), U6.6 (HVOUT17)
/Nixie_Driver/AN_F0: N2.13 (K0), U6.17 (HVOUT10)
/Nixie_Driver/AN_F1: N2.2 (K1), U6.26 (HVOUT1)
/Nixie_Driver/AN_F2: N2.9 (K2), U6.20 (HVOUT7)
/Nixie_Driver/AN_F3: N2.4 (K3), U6.24 (HVOUT3)
/Nixie_Driver/AN_F4: N2.6 (K4), U6.23 (HVOUT4)
/Nixie_Driver/AN_F5: N2.7 (K5), U6.22 (HVOUT5)
/Nixie_Driver/AN_F6: N2.8 (K6), U6.21 (HVOUT6)
/Nixie_Driver/AN_F7: N2.3 (K7), U6.25 (HVOUT2)
/Nixie_Driver/AN_F8: N2.11 (K8), U6.19 (HVOUT8)
/Nixie_Driver/AN_F9: N2.12 (K9), U6.18 (HVOUT9)
/Nixie_Driver/BLANK: J3.8, U4.16 (B4)
/Nixie_Driver/BLANK_C: J4.8, U1.13 (BLANKING), U5.13 (BLANKING), U6.13 (BLANKING)
/Nixie_Driver/CLOCK: J3.5, U4.20 (B1)
/Nixie_Driver/CLOCK_C: J4.5, U1.15 (CLOCK), U5.15 (CLOCK), U6.15 (CLOCK)
/Nixie_Driver/COLON_L_C: J4.9, R15.2
/Nixie_Driver/COLON_R_C: J4.10, R3.2
/Nixie_Driver/DATA: J3.7, U4.17 (B3)
/Nixie_Driver/DATA_1: U5.27 (DI), U6.2 (DO)
/Nixie_Driver/DATA_2: U1.27 (DI), U5.2 (DO)
/Nixie_Driver/DATA_C: J4.7, U6.27 (DI)
/Nixie_Driver/STROBE: J3.6, U4.18 (B2)
/Nixie_Driver/STROBE_C: J4.6, U1.16 (STROBE), U5.16 (STROBE), U6.16 (STROBE)
/U0RXD: TP2.1, U8.36 (U0RXD/GPIO44/CLK_OUT2)
/U0TXD: TP1.1, U8.37 (U0TXD/GPIO43/CLK_OUT1)
/USBD+: J5.A6 (D+), J5.B6 (D+), U8.14 (GPIO20/U1CTS/ADC2_CH9/CLK_OUT1/USB_D+)
/USBD-: J5.A7 (D-), J5.B7 (D-), U8.13 (GPIO19/U1RTS/ADC2_CH8/CLK_OUT2/USB_D-)
/VBUS: F1.2, J5.A4B9 (VBUS), J5.B4A9 (VBUS)
BLANK_ESP32: U4.5 (A4), U8.4 (GPIO4/TOUCH4/ADC1_CH3)
CLOCK_ESP32: U4.1 (A1), U8.7 (GPIO7/TOUCH7/ADC1_CH6)
COLON_L: J3.9, U8.39 (GPIO1/TOUCH1/ADC1_CH0)
COLON_R: J3.10, U8.38 (GPIO2/TOUCH2/ADC1_CH1)
DATA_ESP32: U4.4 (A3), U8.6 (GPIO6/TOUCH6/ADC1_CH5)
GND: BT1.2 (-), C1.2, C2.2, C3.2, C4.2, C5.2, C6.2, C7.2, C8.2, C9.2, C10.2, C11.2, C12.2, C13.2, C14.2, C15.1, D1.2 (A), D2.2 (A), D3.2 (A), J1.4, J3.11, J3.12, J3.13, J3.14, J4.11, J4.12, J4.13, J4.14, J5.A1B12 (GND), J5.B1A12 (GND), J5.S1 (SHIELD), Q1.2 (E), Q2.2 (E), R18.1, R19.1, SW1.2 (B), SW2.2 (B), SW3.2 (B), SW4.2 (B), SW5.2 (B), U1.14 (GND), U2.1 (GND), U3.2 (GND), U3.3 (GND), U4.11 (GND), U5.14 (GND), U6.14 (GND), U7.4 (VSS), U8.1 (GND), U8.40 (GND), U8.41 (GND)
unnamed: BT1.1 (+), C15.2, D4.1 (K), U7.8 (VDD)
unnamed: D1.1 (K), R9.1, U1.1 (VPP)
unnamed: D2.1 (K), R10.1, U5.1 (VPP)
unnamed: D3.1 (K), R13.1, U6.1 (VPP)
unnamed: J2.2, U3.1 (VIN)
unnamed: J5.A5 (CC1), R18.2
unnamed: J5.B5 (CC2), R19.2
unnamed: N1.1 (A), R1.1
unnamed: N2.1 (A), R2.1
unnamed: N3.1 (A), R4.1
unnamed: N4.1 (A), R5.1
unnamed: N5.A, R11.1
unnamed: N7.1 (A), R12.1
unnamed: N8.1 (A), R14.1
unnamed: N9.A, R17.1
unnamed: Q1.1 (B), R3.1
unnamed: N5.C, Q1.3 (C)
unnamed: Q2.1 (B), R15.1
unnamed: N9.C, Q2.3 (C)
unnamed: C13.1, U7.1 (OSCI), Y1.2
unnamed: C14.1, U7.2 (OSCO), Y1.1
SCL: J1.2, R8.1, U7.6 (SCL), U8.17 (GPIO9/TOUCH9/ADC1_CH8/FSPIHD/SUBSPIHD)
SDA: J1.1, R7.1, U7.5 (SDA), U8.12 (GPIO8/TOUCH8/ADC1_CH7/SUBSPICS1)
STROBE_ESP32: U4.3 (A2), U8.5 (GPIO5/TOUCH5/ADC1_CH4)
SW_0: R22.1, SW1.1 (A), U8.22 (GPIO14/TOUCH14/ADC2_CH3/FSPIWP/FSPIDQS/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)
SW_1: R23.1, SW2.1 (A), U8.10 (GPIO17/U1TXD/ADC2_CH6)
SW_2: R24.1, SW3.1 (A), U8.11 (GPIO18/U1RXD/ADC2_CH7/CLK_OUT3)

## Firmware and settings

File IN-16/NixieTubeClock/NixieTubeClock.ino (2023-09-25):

/**
 * Copyright (c) 2023 Yoichi Tanibayashi
 */
#include "Nixie.h"
#include "Button.h"
#include "NetMgr.h"
#include "ModeBase.h"
#include "ModeClock.h"
#include "ModeSetClock.h"
#include "ModeCount.h"
#include "ModeTest1.h"
#include "ModeTest2.h"

static const String MY_NAME = "Nixie Tube Clock";
/**
 * Version X.Y.Z
 * {v0,v1, v2,v3, v4,v5}
 *
 * X = v0 * 10 + v1
 * Y = v2
 * Z = v3
 * v4, v5: 0 (always)
 */
int                 initValVer[NIXIE_NUM_N] = {0,1, 0,0, 0,0};

#define LOOP_DELAY_US   1   // micro sbeconds
#define DEBOUNCE        300 // msec

String dayOfWeekStr[] = {"Sun", "Mon", "Tue", "Wed", "Thu", "Fri", "Sat"};

//======================================================================
// pins
//----------------------------------------------------------------------
#define PIN_I2C_SDA         9
#define PIN_I2C_SCL         8

#define PIN_HV5812_CLK      7
#define PIN_HV5812_STOBE    5
#define PIN_HV5812_DATA     6
#define PIN_HV5812_BLANK    4

#define PIN_COLON_R_TOP     2
#define PIN_COLON_R_BOTTOM  2
#define PIN_COLON_L_TOP     1
#define PIN_COLON_L_BOTTOM  1

#define PIN_BTN0           14
#define PIN_BTN1           17
#define PIN_BTN2           18


uint8_t pinsIn[] = {PIN_BTN0, PIN_BTN1, PIN_BTN2};

uint8_t nixiePins[NIXIE_NUM_N][NIXIE_NUM_DIGIT_N] =
  {
   { 9,  0,  6,  2,  3,  4,  5,  1,  7,  8},
   {15, 14, 18, 12, 11, 10, 19, 13, 17, 16},
   {35, 20, 38, 22, 23, 24, 39, 21, 37, 36},
   {29, 34, 26, 32, 31, 30, 25, 33, 27, 28},
   {55, 54, 58, 52, 51, 50, 59, 53, 57, 56},
   {49, 40, 46, 42, 43, 44, 45, 41, 47, 48}
  };

uint8_t colonPins[NIXIE_COLON_N][NIXIE_COLON_DOT_N] =
  {
   {PIN_COLON_R_TOP},
   {PIN_COLON_L_TOP}
  };

uint8_t intrPin0 = digitalPinToInterrupt(PIN_BTN0);
uint8_t intrPin1 = digitalPinToInterrupt(PIN_BTN1);
uint8_t intrPin2 = digitalPinToInterrupt(PIN_BTN2);

//======================================================================
// NetMgr
//----------------------------------------------------------------------
NetMgr  netMgr;
boolean wifiActive      = false;
boolean prev_wifiActive = false;

//======================================================================
// NTP
//----------------------------------------------------------------------
const String        NTP_SVR[]    = {"pool.ntp.org",
                                    "ntp.nict.jp",
                                    "time.google.com"};
const unsigned long NTP_INTERVAL = 1 * 60 * 1000; // msec
unsigned long       ntpLast      = 0;
boolean             ntpActive    = false;

//======================================================================
// RTC DS3231
//----------------------------------------------------------------------
//RTC_DS3231 Rtc;
RTC_PCF8563 Rtc;

//======================================================================
// Nixie Array
//----------------------------------------------------------------------
NixieArray nixieArray(PIN_HV5812_CLK,  PIN_HV5812_STOBE,
                      PIN_HV5812_DATA, PIN_HV5812_BLANK,
                      nixiePins, colonPins);
//======================================================================
// Modes
//----------------------------------------------------------------------
ModeClock modeClock = ModeClock(&nixieArray);
ModeTest1 modeTest1 = ModeTest1(&nixieArray);
ModeTest2 modeTest2 = ModeTest2(&nixieArray);
ModeSetClock modeSetClock = ModeSetClock(&nixieArray);
ModeCount modeCount = ModeCount(&nixieArray);

ModeBase* Mode[] = {&modeClock, &modeSetClock, &modeCount, &modeTest1, &modeTest2};
const unsigned long MODE_N = sizeof(Mode) / sizeof(&Mode[0]);
const unsigned int MODE_CLOCK     = 0;
const unsigned int MODE_SET_CLOCK = 1;
const unsigned int MODE_COUNT     = 2;
const unsigned int MODE_TEST1     = 3;
const unsigned int MODE_TEST2     = 4;

long curMode = 0;
long prevMode = -1;

//======================================================================
// Buttons
//----------------------------------------------------------------------
Button b0 = Button(PIN_BTN0, "BTN0");
Button b1 = Button(PIN_BTN1, "BTN1");
Button b2 = Button(PIN_BTN2, "BTN2");

Button* Btn[] = {&b0, &b1, &b2};

const unsigned long BTN_N = sizeof(Btn) / sizeof(&Btn[0]);

//======================================================================
// global variables
//----------------------------------------------------------------------
unsigned long loopCount = 0;
unsigned long curMsec   = 0; // msec
unsigned long prevMsec  = 0; // msec

//======================================================================
/**
 *
 */
void ntp_adjust() {
  struct tm time_info;

  if (ntpActive) {
    log_i("ntp_adjust> ntpActive=true");
  } else {
    log_i("ntp_adjust> ntpActive=false");
    return;
  }
  
  disableIntr();
  getLocalTime(&time_info); // NTP
  log_i("ntp_adjust> %04d/%02d/%02d(%s) %02d:%02d:%02d",
        time_info.tm_year + 1900,
        time_info.tm_mon + 1,
        time_info.tm_mday,
        dayOfWeekStr[time_info.tm_wday].c_str(),
        time_info.tm_hour,
        time_info.tm_min,
        time_info.tm_sec);

  if ( time_info.tm_year + 1900 > 2000 ) {
    DateTime now = DateTime(time_info.tm_year + 1900,
                            time_info.tm_mon + 1,
                            time_info.tm_mday,
                            time_info.tm_hour,
                            time_info.tm_min,
                            time_info.tm_sec);
    Rtc.adjust(now);
  } else {
    log_i(" .. ignored !");
  }
  enableIntr();
} // ntp_adjust()

/**
 *
 */
unsigned long change_mode(unsigned long mode=MODE_N) {
  // log_i("change_mode> mode=%d/%d\n", (int)mode, MODE_N);
  prevMode = curMode;
  if (mode < MODE_N) {
    curMode = mode;
  } else if (mode == MODE_N) {
    curMode = (curMode + 1) % MODE_N;
  } else {
    curMode = (curMode + MODE_N - 1) % MODE_N;
  }
  //log_i("change_mode> curMode=%d:%s\n",
  //                (int)curMode, Mode[curMode]->name().c_str());

  nixieArray.end_all_effect();

  return curMode;
} // change_mode()

/**
 * RTC読込中に 割り込みがかかると落ちることがある
 * 設定ファイル読込中に 割り込みがかかると落ちることがある
 */
void IRAM_ATTR btn_intr_hdr() {
  static unsigned long prev_ms = 0;
  unsigned long        cur_ms = millis();

  if ( cur_ms - prev_ms < DEBOUNCE ) {
    return;
  }
  prev_ms = cur_ms;

  for (int b=0; b < BTN_N; b++) {
    if ( Btn[b]->get() ) {
      // log_i("btn_intr_hdr> ");
      // Btn[b]->print();
      
      Mode[curMode]->btn_intr_hdr(curMsec, Btn[b]);
    }
  } // for(b)
}


/**
 *
 */
void btn_loop_hdr(unsigned long cur_ms, Button *btn) {
  log_i("btn_loop_hdr> %s", btn->toString().c_str());

  if ( btn->get_name() == "BTN0" ) {
    if ( btn->get_click_count() >= 1 ) {
      if ( Btn[1]->get_value() == Button::ON ) {
        if ( curMode == MODE_CLOCK ) {
          change_mode(MODE_COUNT);
          return;
        }
        if ( curMode == MODE_COUNT ) {
          change_mode(MODE_CLOCK);
          return;
        }
      }
    }

    if ( btn->get_click_count() >= 3 ) {
      change_mode();
      if ( curMode == MODE_SET_CLOCK ) {
        change_mode();
      }
      return;
    }

    if ( btn->get_click_count() == 2 && curMode == MODE_CLOCK ) {
      log_i("btn_loop_hdr> netMgr.cur_mode=0x%02X", netMgr.cur_mode);
      wifiActive = false;
      prev_wifiActive = false;
      ntpActive = false;
      if ( netMgr.cur_mode == NetMgr::MODE_AP_LOOP
           || netMgr.cur_mode == NetMgr::MODE_WIFI_OFF ) {
        //netMgr.cur_mode = NetMgr::MODE_START;
        log_i("btn_loop_hdr> Reboot");
        log_i("==========");
        ESP.restart();
      } else {
        netMgr.cur_mode = NetMgr::MODE_AP_INIT;
      }
      log_i("btn_loop_hdr> netMgr.cur_mode=0x%02X", netMgr.cur_mode);
      delay(500);
      return;
    }
  }

  Mode[curMode]->btn_loop_hdr(cur_ms, btn);
} // btn_loop_hdr()

/**
 *
 */
void enableIntr() {
  attachInterrupt(intrPin0, btn_intr_hdr, CHANGE);
  attachInterrupt(intrPin1, btn_intr_hdr, CHANGE);
  attachInterrupt(intrPin2, btn_intr_hdr, CHANGE);
}

/**
 *
 */
void disableIntr() {
  detachInterrupt(intrPin0);
  detachInterrupt(intrPin1);
  detachInterrupt(intrPin2);
}

//=======================================================================
/**
 *
 */
void setup() {
  Serial.begin(115200);
  log_i("setup> begin");

  for (int i=0; i < MODE_N; i++) {
    log_i("Mode[%d]:%s", i, Mode[i]->name().c_str());
  }
  
  log_i("NTP servers:");
  for (int i=0; i < 3; i++) {
    log_i(" %s", NTP_SVR[i].c_str());
  }

  //---------------------------------------------------------------------
  // グローバルオブジェクト・変数の初期化
  //- - - - - - - - - - - - - - - - - - - - - - - - - - - - - - - - - - -
  NetMgr::myName = MY_NAME;
  nixieArray.brightness = BRIGHTNESS_RESOLUTION;
  ntpActive = false;

  log_i("setup> RTC begin");
  Wire.setPins(PIN_I2C_SDA, PIN_I2C_SCL);
  Rtc.begin(&Wire);
  unsigned long sec = Rtc.now().second();
  randomSeed(sec); // TBD

  prevMsec = millis();
  curMsec = prevMsec;
  //---------------------------------------------------------------------
  // 初期状態表示
  //- - - - - - - - - - - - - - - - - - - - - - - - - - - - - - - - - - -
  nixieArray.display(curMsec);
  //---------------------------------------------------------------------
  // 割り込み初期化
  //- - - - - - - - - - - - - - - - - - - - - - - - - - - - - - - - - - -
  log_i("digitalPinToInterrupt:");
  log_i(" %d --> %d", PIN_BTN0, intrPin0);
  log_i(" %d --> %d", PIN_BTN1, intrPin1);
  log_i(" %d --> %d", PIN_BTN2, intrPin2);


  // !! Important !!
  // 
  // 設定ファイル読込中に 割り込みがかかると落ちることがある
  enableIntr();
} // setup()

//=======================================================================
/**
 *
 */
void loop() {
  mode_t   netmgr_mode;

  disableIntr();
  DateTime now = Rtc.now();
  enableIntr();

  prevMsec = curMsec;
  curMsec = millis();
  loopCount++;

  //---------------------------------------------------------------------
  // NetMgr
  netmgr_mode = netMgr.loop();
  prev_wifiActive = wifiActive;
  if (netmgr_mode == NetMgr::MODE_WIFI_ON) {
    wifiActive = true;
    ntpActive = true;
    if ( wifiActive != prev_wifiActive ) {
      log_i("loop> WiFi ON");
      configTime(9 * 3600L, 0,
                 NTP_SVR[0].c_str(),
                 NTP_SVR[1].c_str(),
                 NTP_SVR[2].c_str());
      ntp_adjust();
    }
  } else if ( netmgr_mode == NetMgr::MODE_WIFI_OFF ) {
    wifiActive = false;
    ntpActive = false;
    if ( wifiActive != prev_wifiActive ) {
      log_i("loop> WiFi OFF");
      netMgr.cur_mode = NetMgr::MODE_START;
    }
  }
  
  //---------------------------------------------------------------------
  // NTP
  if ((curMsec - ntpLast) >= NTP_INTERVAL) {
    ntpLast = curMsec;
    ntp_adjust();
  }

  //---------------------------------------------------------------------
  if (loopCount % 3000 == 0) {
    log_i("loop> now=%04d/%02d/%02d(%s) %02d:%02d:%02d, brightness=%d/%d",
          now.year(), now.month(), now.day(),
          dayOfWeekStr[now.dayOfTheWeek()].c_str(),
          now.hour(), now.minute(), now.second(),
          nixieArray.brightness, BRIGHTNESS_RESOLUTION);
  }

  //---------------------------------------------------------------------
  // check buttions
  for (int b=0; b < BTN_N; b++) {
    if ( ! Btn[b]->get() ) {
      continue;
    }

    btn_loop_hdr(curMsec, Btn[b]);
  } // for(b)

  //---------------------------------------------------------------------
  // モード実行
  if (curMode != prevMode) {
    // モード変更時の初期化
    Mode[curMode]->init(curMsec, now, initValVer);
    prevMode = curMode;
  } else {
    // 各モードの loop() 実行
    stat_t stat = Mode[curMode]->loop(curMsec, now);
    switch (stat) {
    case ModeBase::STAT_BACK_MODE:
      log_i("loop> stat=0x%X, curMode=%d, prevMode=%d",
            (int)stat, (int)curMode, (int)prevMode);
      change_mode(MODE_N + 1);
      break;

    case ModeBase::STAT_NEXT_MODE:
      log_i("loop> stat=0x%X", (int)stat);
      change_mode();
      break;

    default:
      break;
    } // switch(stat)
  }

  //---------------------------------------------------------------------
  // 表示
  nixieArray.display(curMsec);

  //---------------------------------------------------------------------
  delayMicroseconds(LOOP_DELAY_US);
} // loop()

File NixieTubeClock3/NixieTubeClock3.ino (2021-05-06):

/*
 * (c) 2020 Yoichi Tanibayashi
 */
#include "Nixie.h"
#include "Button.h"
#include "ModeBase.h"
#include "ModeTest1.h"
#include "ModeTest2.h"
#include "ModeClock1.h"
#include "ModeClock2.h"

#define LOOP_DELAY_US       5 // micro sbeconds
#define WIFI_TRY_MAX       10 // count
#define DEBOUNCE          200 // msec

const char* SSID = "fablabkannai";
const char* SSID_PW = "kannai201";

const char* ntpSvr[] = {"ntp.nict.jp", "time.google.com", ""};

//============================================================================
#define PIN_HV5812_CLK     26
#define PIN_HV5812_STOBE   13
#define PIN_HV5812_DATA    14
#define PIN_HV5812_BLANK    4

#define PIN_COLON_R_TOP    16
#define PIN_COLON_R_BOTTOM 16
#define PIN_COLON_L_TOP    17
#define PIN_COLON_L_BOTTOM 17

#define PIN_LED            27

#define PIN_BTN0           33
#define PIN_BTN1           34
#define PIN_BTN2           35
#define BTN_N               3

//======================================================================
/* for NTP */
const unsigned long ntpInterval = 1000 * 20; // msec
unsigned long       ntpLast = 0;
boolean             ntpActive = false;

//======================================================================
/* RTC DS3231 */
RTC_DS3231 Rtc;
char* dayOfTheWeek[7] = {"Sun", "Mon", "Tue", "Wed", "Thu", "Fri", "Sat"};

//======================================================================
uint8_t pinsIn[] = {PIN_BTN0, PIN_BTN1, PIN_BTN2};
//----------------------------------------------------------------------
uint8_t nixiePins[NIXIE_NUM_N][NIXIE_NUM_DIGIT_N] =
  {{ 9,  0,  1,  2,  3,  4,  5,  6,  7,  8},
   {19, 10, 11, 12, 13, 14, 15, 16, 17, 18},
   {29, 20, 21, 22, 23, 24, 25, 26, 27, 28},
   {39, 30, 31, 32, 33, 34, 35, 36, 37, 38},
   {49, 40, 41, 42, 43, 44, 45, 46, 47, 48},
   {59, 50, 51, 52, 53, 54, 55, 56, 57, 58} };
//----------------------------------------------------------------------
uint8_t colonPins[NIXIE_COLON_N][NIXIE_COLON_DOT_N] =
  {{PIN_COLON_R_TOP},
   {PIN_COLON_L_TOP} };
//----------------------------------------------------------------------
NixieArray nixieArray(PIN_HV5812_CLK,  PIN_HV5812_STOBE,
                      PIN_HV5812_DATA, PIN_HV5812_BLANK,
                      nixiePins, colonPins);
Button *btnObj[3];
//----------------------------------------------------------------------
unsigned long loopCount  = 0;
unsigned long curMsec    = 0; // msec
unsigned long prevMsec   = 0;
//----------------------------------------------------------------------
int curTube = 0;
int curDigit = 0;
//----------------------------------------------------------------------
#define MODE_N 3
ModeBase *Mode[MODE_N];
long curMode = 0;
long prevMode = -1;

//======================================================================
void ntp_adjust() {
  struct tm time_info;

  getLocalTime(&time_info);
  DateTime now = DateTime(time_info.tm_year + 1900,
                          time_info.tm_mon + 1,
                          time_info.tm_mday,
                          time_info.tm_hour,
                          time_info.tm_min,
                          time_info.tm_sec);
  Rtc.adjust(now);

  char dt_str[128];
  sprintf(dt_str, "%04d/%02d/%02d(%s) %02d:%02d:%02d",
          time_info.tm_year + 1900, time_info.tm_mon + 1, time_info.tm_mday,
          dayOfTheWeek[time_info.tm_wday],
          time_info.tm_hour, time_info.tm_min, time_info.tm_sec);
  Serial.println("ntp_adjust> " + String(dt_str));
} // ntp_adjust()

long change_mode() {
  nixieArray.end_all_effect();
  prevMode = curMode;
  curMode = (curMode + 1) % MODE_N;
  Serial.println("change_mode(): curMode=" + String(curMode));
  return curMode;
} // change_mode()

void btn_handler() {
  static unsigned long prev_msec = 0;
  unsigned long cur_msec = millis();

  Serial.println("btn_handler>");
  
  if ( cur_msec - prev_msec < DEBOUNCE ) {
    return;
  }
  prev_msec = cur_msec;

  for (int b=0; b < BTN_N; b++) {
    if ( btnObj[b]->get() ) {
      if ( b == 0 && btnObj[b]->get_click_count() >= 2 ) {
	change_mode();
      }
      btnObj[b]->print();
      Mode[curMode]->btn_intr(curMsec, btnObj[b]);
    }
  } // for(b)
} // btn_handler

//=======================================================================
void setup() {
  Serial.begin(115200);
  randomSeed(analogRead(0));
  Serial.println("setup> begin");
  
  //---------------------------------------------------------------------
  // グローバルオブジェクト・変数の初期化
  //- - - - - - - - - - - - - - - - - - - - - - - - - - - - - - - - - - -
  WiFi.begin(SSID, SSID_PW);

  Serial.println("setup> RTC begin");
  Rtc.begin();
  unsigned long sec = Rtc.now().second();
  Serial.println("setup> sec=" + String(sec));
  randomSeed(sec);

  /*
  nixieArray = new NixieArray(PIN_HV5812_CLK,  PIN_HV5812_STOBE,
                              PIN_HV5812_DATA, PIN_HV5812_BLANK,
                              nixiePins, colonPins);
  */
  nixieArray.blightness = 10;
  //- - - - - - - - - - - - - - - - - - - - - - - - - - - - - - - - - - -
  // 各モードオブジェクト生成
  //Mode[0] = new ModeClock1(nixieArray);
  Mode[0] = new ModeClock2(&nixieArray);
  Mode[1] = new ModeTest1(&nixieArray);
  Mode[2] = new ModeTest2(&nixieArray);

  //- - - - - - - - - - - - - - - - - - - - - - - - - - - - - - - - - - -
  // ボタンの初期化
  btnObj[0] = new Button(PIN_BTN0, "BTN0");
  btnObj[1] = new Button(PIN_BTN1, "BTN1");
  btnObj[2] = new Button(PIN_BTN2, "BTN2");
  //-   -   -   -   -   -   -   -   -   -   -   -   -   -   -   -   -   -
  uint8_t intr_pin0 = digitalPinToInterrupt(PIN_BTN0);
  uint8_t intr_pin1 = digitalPinToInterrupt(PIN_BTN1);
  uint8_t intr_pin2 = digitalPinToInterrupt(PIN_BTN2);
  Serial.println("digitalPinToInterrupt:");
  Serial.println(" " + String(PIN_BTN0) + " --> " + String(intr_pin0));
  Serial.println(" " + String(PIN_BTN1) + " --> " + String(intr_pin1));
  Serial.println(" " + String(PIN_BTN2) + " --> " + String(intr_pin2));

  attachInterrupt(intr_pin0, btn_handler, CHANGE);
  attachInterrupt(intr_pin1, btn_handler, CHANGE);
  attachInterrupt(intr_pin2, btn_handler, CHANGE);
  //- - - - - - - - - - - - - - - - - - - - - - - - - - - - - - - - - - -
  // 時間
  prevMsec = millis();
  curMsec = millis();
  //---------------------------------------------------------------------
  nixieArray.display(curMsec); // 初期状態表示
  //---------------------------------------------------------------------

  //---------------------------------------------------------------------
  // WIFI and NTP
  for (int i=0; i < WIFI_TRY_MAX; i++) {
    Serial.println("waiting WiFi: " + String(SSID));
    delay(500);
    if (WiFi.status() == WL_CONNECTED) {
      Serial.println("Connected WiFi: " + String(SSID));
      Serial.println("IP addr: " + WiFi.localIP().toString());

      configTime(9 * 3600L, 0, ntpSvr[0], ntpSvr[1], ntpSvr[2]);
      ntpActive = true;
      ntp_adjust();
      break;
    }
  }
  if ( ! ntpActive ) {
    WiFi.mode(WIFI_OFF);
    Serial.println("setup> WiFi OFF");
  }

} // setup()
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

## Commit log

2021-05-16 [fix] web_svr.enableDelay(false) and more
    [NixieTubeClock.ino]
2021-06-26 FIX some warnings, and ADD [BTN1]+[BTN0] to Counter
    [NixieTubeClock.ino]
2021-08-01 Add: NeoPixel samples
2021-08-10 Start: 0.8.7(current)
2021-08-21 Start: 0.8.8(current)
2021-08-22 Start: 0.8.9(current)
2021-11-07 ADD: Stand/
    [Stand1.f3d]
2021-11-07 FIX: brightness of ModeSetClock
    [NixieTubeClock.ino]
2021-11-07 FIX: typo: blightness -> brightness
    [NixieTubeClock.ino]
2021-11-09 ADD: Stand2/
    [Stand2.f3d]
2021-11-10 ADD: Stand3/
    [Stand3.f3d]
2021-11-10 ADD: buttons0.jpg
2021-11-11 FIX: some buf fixes
    [NixieTubeClock.ino, NixieTubeClock_4.ino]
2023-04-02 BTN0: 時刻表示
2023-04-02 BTN0: 時刻表示 etc.
2023-09-14 START: IN-16
    [Bottom_Drawing_0821.dxf, Bottom_Drawing_0827.dxf, Bottom_Rubber_Foot.dxf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]
2023-09-27 ADD: IN-16/tests/clock02/: OLED + Nixie Tube test
